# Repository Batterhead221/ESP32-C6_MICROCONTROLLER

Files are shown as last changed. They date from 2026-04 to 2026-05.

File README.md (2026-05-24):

# ESP32-C6_MICROCONTROLLER

<p align="center">
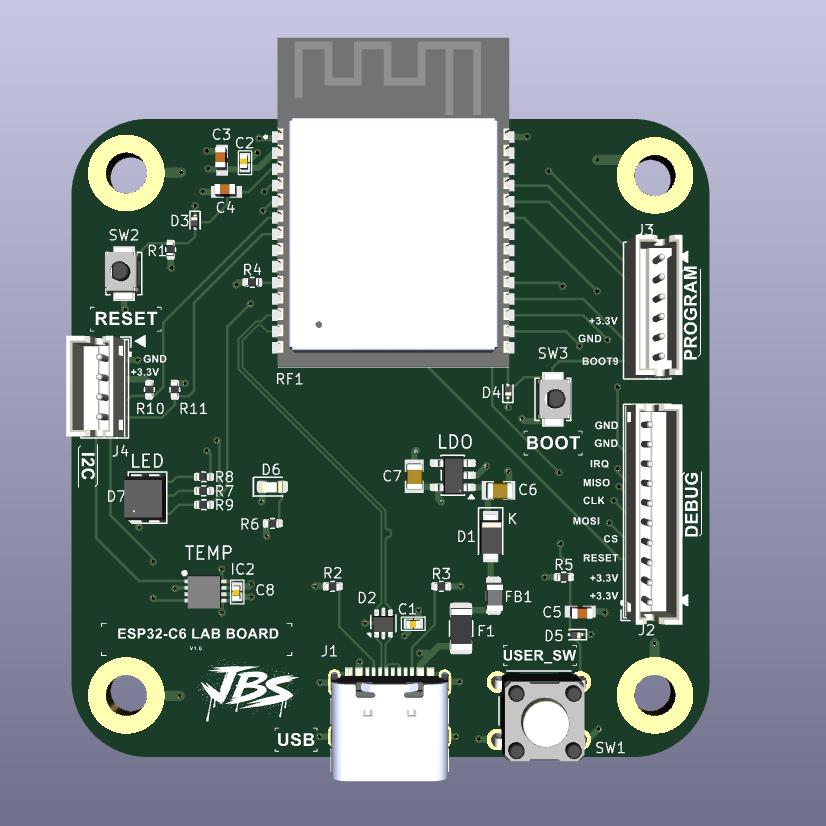
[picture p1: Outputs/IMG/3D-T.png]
ESP32-C6_MICROCONTROLLER top 3D board render
  
</p>

<p align="center">
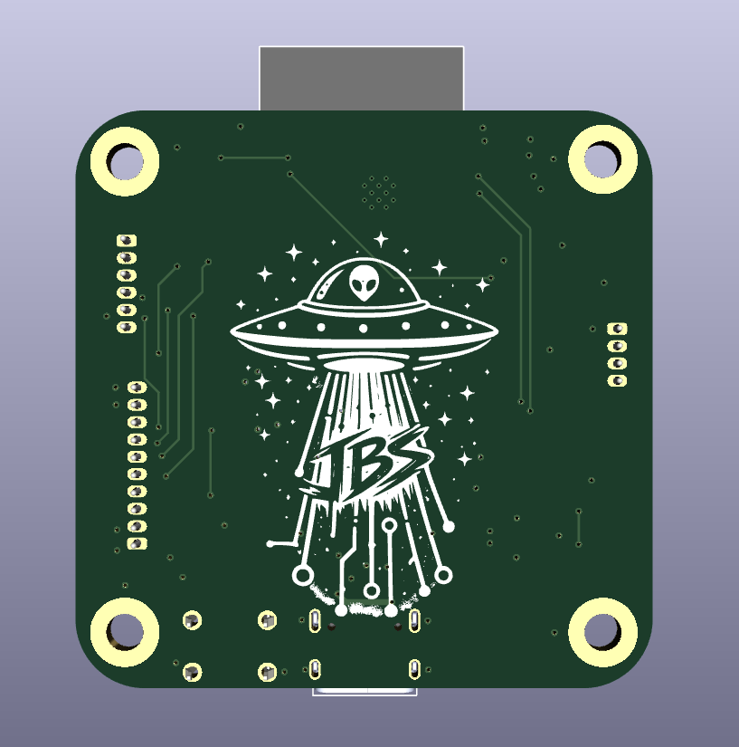
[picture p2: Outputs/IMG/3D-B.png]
ESP32-C6_MICROCONTROLLER bottom 3D board render
  
</p>

Custom ESP32-C6 development board with USB-C power, RGB status LED, user input, I2C expansion, OLED support, UART programming access, and onboard temperature/humidity sensing.

This board is a small ESP32-C6 bring-up and sensor demo platform. It was designed to verify core power, boot/programming flow, GPIO, RGB LED control, I2C device detection, OLED output, and live environmental sensor readings.

## Project Status

Bring-up demo verified.

The board has successfully run a combined test with:

- RGB LED control
- User button input
- I2C bus scan
- OLED output
- Live temperature/humidity readout
- UART programming through the J3 program header

## Demo Features

- ESP32-C6 microcontroller core
- USB-C power input
- 3.3V regulation
- RGB status LED
- User button
- I2C expansion header
- OLED display support
- Onboard temperature/humidity sensor
- UART programming/debug header
- Reset and boot control for bring-up

## System Role

```text
USB-C / bench power
        ↓
ESP32-C6_MICROCONTROLLER
        ↓ I2C
OLED display + temp/humidity sensor
        ↓
bring-up demo / serial debug output
```

## Key Specs

| Item | Value |
|---|---|
| MCU | ESP32-C6 |
| Main rail | +3.3V |
| Power input | USB-C |
| Programming path verified | UART through J3 program header |
| Display interface | I2C OLED |
| Sensor interface | I2C temp/humidity sensor |
| OLED address | `0x3C` |
| Temp/humidity sensor address | `0x44` |
| RGB LED behavior | Active-low |
| Board role | ESP32-C6 bring-up/demo board |

## Verified Working

- USB-C power input
- 3.3V regulation
- ESP32-C6 boot from flash
- UART programming through J3
- Reset button
- Boot button/manual boot sequence
- User button
- RGB LED
- I2C bus
- OLED display at `0x3C`
- Temperature/humidity sensor at `0x44`

## Verified GPIO Map

| GPIO | Function |
|---:|---|
| GPIO3 | RGB red |
| GPIO4 | RGB green |
| GPIO5 | RGB blue |
| GPIO23 | User switch |
| GPIO6 | I2C SDA |
| GPIO7 | I2C SCL |

## RGB LED Notes

The RGB LED is active-low.

```text
GPIO LOW  → LED color ON
GPIO HIGH → LED color OFF
```

Firmware should invert the LED logic when controlling the status LED.

## I2C Devices

The following I2C devices were detected during bring-up:

| Address | Device |
|---:|---|
| `0x3C` | OLED display |
| `0x44` | Temperature/humidity sensor |

## Sample Verified Sensor Reading

Example live reading from bring-up:

```text
Temperature: 29.2 C
Humidity:    35.0 %RH
```

## UART Programming Notes

UART programming through the **J3 program header** is working.

Working connections:

| USB-UART adapter | ESP32-C6 board |
|---|---|
| TX | ESP_RXD |
| RX | ESP_TXD |
| GND | GND |

## Manual Upload Sequence

Current working upload sequence:

1. Hold **BOOT**.
2. Start upload.
3. Tap **RESET** when the tool begins connecting.
4. Release **BOOT** after connection.
5. Press **RESET** after upload to run the application.

## Native USB Status

Native USB enumeration still needs separate debug and validation.

Current programming flow uses UART through the J3 program header.

## Bring-Up Checklist

1. Inspect USB-C and regulator soldering.
2. Power from USB-C and confirm +3.3V.
3. Connect USB-UART adapter to J3.
4. Use the manual BOOT/RESET upload sequence.
5. Verify boot from flash.
6. Run I2C scanner.
7. Confirm OLED at `0x3C`.
8. Confirm temp/humidity sensor at `0x44`.
9. Verify RGB LED channels.
10. Verify user button input.
11. Run combined OLED + sensor + LED demo.

## Open Items

- Validate native USB enumeration.
- Improve programming flow beyond manual UART boot sequence.
- Add screenshots/photos of OLED and sensor demo.
- Add firmware example to the repository.

## Repository Output Images

Expected image paths for GitHub README rendering:

```text
Outputs/
  IMG/
    3D-T.png
    3D-B.png
    SCHEMATIC.png
    L1-SIG.png
    L2-GND.png
```

## Safety / Design Note

ESP32-C6_MICROCONTROLLER is a low-voltage development board. Verify regulator output, USB wiring, and UART adapter voltage level before connecting external hardware.

Designed & engineered by Brandon Shelly.

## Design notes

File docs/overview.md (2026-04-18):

#ESP32-C6_BOARD

## OVERVIEW

EMBEDDED HARDWARE / MICROCONTROLLER PCB DESIGN PROJECT

WI-FI / BLUETOOTH CUSTOM EMBEDDED MICROCONTROLLER PCB DESIGNED FOR BRING-UP, DEBUG, AND INTERFACE VALIDATION

## CREATED TO DEMONSTRATE:
- SCHEMATIC CAPTURE
- PCB LAYOUT
- DFM-AWARE DESIGN
- BRING-UP AND TEST PLANNING
- HARDWARE DOCUMENTATION

## KEY FEATURES
- [ESP32C6]
- [USB-C POWER INPUT]
- [UART]
- [DEBUG / PROGRAMMING INTERFACE]
- [TEMP/WI-FI/BLUETOOTH]

## PROJECT STATUS
REVISION: V1.0  
STATUS: WORKING

DESIGNED & ENGINEERED BY BRANDON SHELLY

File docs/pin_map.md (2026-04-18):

GPIO3 = RED
GPIO4 = GREEN
GPIO5 = BLUE
GPIO23 = USER BUTTON
GPIO6 = SDA
GPIO7 = SCL
OLED = 0x3C
HDC302x = 0x44

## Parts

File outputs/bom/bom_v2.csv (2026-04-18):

BOM_V2
BOM
Id | Designator | Footprint | Quantity | Designation | Supplier and ref | LCSC
1 | J3 | JST_ZH_B6B-ZR_1x06_P1.50mm_Vertical | 1 | PROGRAM | DNP | DNP
2 | J2 | JST_ZH_B10B-ZR_1x10_P1.50mm_Vertical | 1 | DEBUG | DNP | DNP
3 | SW2 | SW_SPST_B3U-1000P | 1 | RESET | B3U-1100P-B | C4364316
4 | USER_SW | SW_TH_Tactile_Omron_B3F-100x | 1 | SW1 | DNP | DNP
5 | SW3 | SW_SPST_B3U-1000P | 1 | BOOT | B3U-1100P-B | C4364316
6 | C3,C5,C4 | CAP 0603 | 3 | 1U | CC0603KRX7R9BB105 | C559769
7 | C2,C1,C8 | CAP 0402 | 3 | 100N | CC0402KRX7R9BB104 | C131394
8 | U1 | SOT-23-5 | 1 | LDO | AP2112K-3.3TRG1 | C23380830
9 | J4 | JST_ZH_B4B-ZR_1x04_P1.50mm_Vertical | 1 | I2C | DNP | DNP
10 | D1 | Nexperia_CFP3_SOD-123W | 1 | 1N5817 | 1N5817W | C727113
11 | R7,R9,R8,R6 | R_0402_1005Metric | 4 | 1K | RC0402JR-071KL | C105637
12 | F1 | Fuse_1206_3216Metric | 1 | 1A | JFC1206-1100FS | C136343
13 | R2,R3 | R_0402_1005Metric | 2 | 5K1 | 0402WGF5101TCE | C25905
14 | C7,C6 | 1UF 0805 | 2 | 1U | CC0805KKX7R8BB105 | C91186
15 | U2 | SON50P250X250X80-9N-D | 1 | LDO | HDC3020DEFR | C7472806
16 | R10,R11 | R_0402_1005Metric | 2 | 2K2 | AC0402FR-072K2L | C144773
17 | FB1 | L_0805_2012Metric | 1 | 22 OHM FERRITE BEAD | BLM21PG220SN1D | C88993
18 | R1,R5,R4 | R_0402_1005Metric | 3 | 10K | 0402 ±1% 10K | C2889342
19 | D4,D3,D5 | D_SOD-923 | 3 | ESD9B3.3 | ESD9B3.3ST5G | C96512
20 | D7 | LED_Cree-PLCC4_3.2x2.8mm_CCW | 1 | RGB_LED | CLV1L-FKB-CJ1N1E1BB7B3B3
21 | D2 | SOT-666 | 1 | USBLC6-2P6 | USBLC6-2P6 | C15999
22 | J1 | USB_C_Receptacle_G-Switch_GT-USB-7010ASV | 1 | USB_C | GT-USB-7010ASV | C2988369
23 | D6 | LED_0603_1608Metric | 1 | GREEN | YLED0603G | C19273151
24 | U3 | XCVR_ESP32-C6-WROOM-1-N8 | 1 | ESP32-C6-WROOM-1-N8 | ESP32-C6-WROOM-1-N8 | C5366877

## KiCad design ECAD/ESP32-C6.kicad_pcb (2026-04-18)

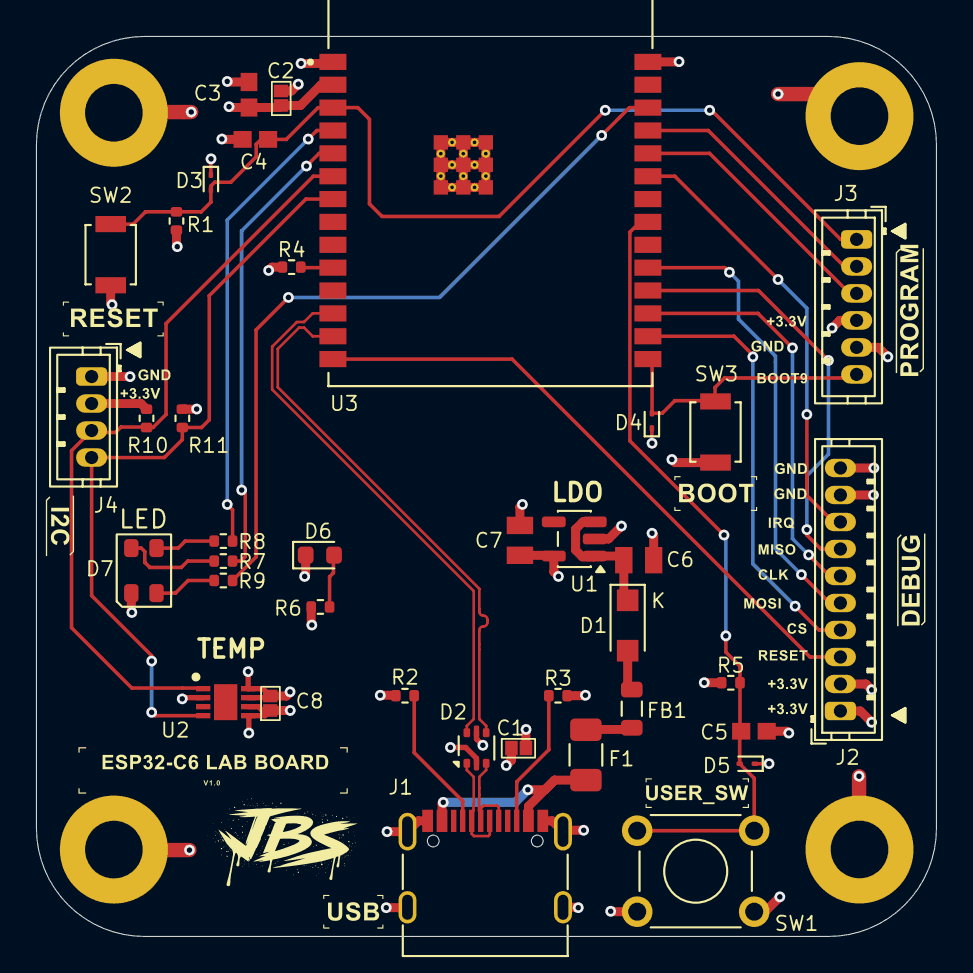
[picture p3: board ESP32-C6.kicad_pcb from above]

Board: 4 copper layers, 50.0 x 50.0 mm, 42 parts (0 on the bottom side), 33 nets.

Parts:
C1, C2, C8: 100N; CAP 0402
C3, C4, C5: 1U; CAP 0603
C6, C7: 1U; 1UF 0805
D1: 1N5817; Nexperia_CFP3_SOD-123W
D2: USBLC6-2P6; SOT-666
D3, D4, D5: ESD9B3.3; D_SOD-923
D6: GREEN; LED_0603_1608Metric
D7: RBG_LED; LED_Cree-PLCC4_3.2x2.8mm_CCW
F1: 1A; Fuse_1206_3216Metric
FB1: 22; L_0805_2012Metric
H1, H2, H3, H4: M3; MountingHole_3.2mm_Pad
J1: USB_C; USB_C_Receptacle_G-Switch_GT-USB-7010ASV
J2: SWD; JST_ZH_B10B-ZR_1x10_P1.50mm_Vertical
J3: PROGRAM; JST_ZH_B6B-ZR_1x06_P1.50mm_Vertical
J4: S2C; JST_ZH_B4B-ZR_1x04_P1.50mm_Vertical
R1, R4, R5: 10K; R_0402_1005Metric
R2, R3: 5K1; R_0402_1005Metric
R6, R7, R8, R9: 1K; R_0402_1005Metric
R10, R11: 2K2; R_0402_1005Metric
SW1: SW_DPST; SW_TH_Tactile_Omron_B3F-100x
SW2: RESET; SW_SPST_B3U-1000P
SW3: SW_SPST_B3U-1000P
U1: LDO; SOT-23-5
U2: HDC3020DEFR; SON50P250X250X80-9N-D
U3: ESP32-C6-WROOM-1-N8; XCVR_ESP32-C6-WROOM-1-N8

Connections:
+3.3V: C1.1, C2.1, C3.1, C7.1, C8.1, D2.5 (Vbus), D7.1 (A), J2.1, J2.2, J3.4, J4.2, R1.1, R4.1, R5.1, R6.2, R10.1, R11.1, U1.5 (VOUT), U2.5 (VDD), U2.6 (~RESET), U3.2 (3V3)
+5V: C6.1, D1.1 (K), U1.1 (VIN), U1.3 (EN)
/BOOT9: D4.2 (A2), J3.6, SW3.2 (B), U3.15 (IO9)
/B_LED: R7.2, U3.5 (IO5)
/CC1: J1.A5 (CC1), R2.1
/CC2: J1.B5 (CC2), R3.1
/CLK: J2.6, U3.17 (IO19)
/CS: J2.4, U3.16 (IO18)
/D+: D2.3 (I/O2), J1.A6 (D+), J1.B6 (D+)
/D-: D2.1 (I/O1), J1.A7 (D-), J1.B7 (D-)
/ESP_EN: C4.1, D3.2 (A2), J3.1, R1.2, SW2.2 (B), U3.3 (EN)
/ESP_RXD: J3.3, U3.24 (RXD0/GPIO17)
/ESP_TXD: J3.2, U3.25 (TXD0/GPIO16)
/G_LED: R8.2, U3.4 (IO4)
/IRQ: J2.8, U3.23 (IO15)
/MISO: J2.7, U3.18 (IO20)
/MOSI: J2.5, U3.19 (IO21)
/RESET: J2.3, U3.14 (IO13)
/R_RED: R9.2, U3.26 (IO3)
/SCL: J4.4, R11.2, U2.4 (SCL), U3.7 (IO7)
/SDA: J4.3, R10.2, U2.1 (SDA), U3.6 (IO6)
/USB_D+: D2.4 (I/O2+), U3.13 (IO12)
/USB_D-: D2.6 (I/O1+), U3.12 (IO11)
/USR_SW: C5.1, D5.2 (A2), R5.2, SW1.2 (B), U3.21 (IO23)
GND: C1.2, C2.2, C3.2, C4.2, C5.2, C6.2, C7.2, C8.2, D2.2 (GND), D3.1 (A1), D4.1 (A1), D5.1 (A1), D6.1 (K), H1.1, H2.2, H3.4, H4.3, J1.A1 (GND), J1.A12 (GND), J1.B1 (GND), J1.B12 (GND), J1.S1 (SHIELD), J2.9, J2.10, J3.5, J4.1, R2.2, R3.2, SW1.1 (A), SW2.1 (A), SW3.1 (A), U1.2 (GND), U2.2 (ADDR), U2.7 (ADDR1), U2.8 (GND), U3.1 (GND), U3.28 (GND__1), U3.29 (GND__10)
unnamed: D1.2 (A), FB1.2
unnamed: D6.2 (A), R6.1
unnamed: D7.4 (BK), R7.1
unnamed: D7.3 (GK), R8.1
unnamed: D7.2 (RK), R9.1
unnamed: F1.1, J1.A4 (VBUS), J1.A9 (VBUS), J1.B4 (VBUS), J1.B9 (VBUS)
unnamed: F1.2, FB1.1
unnamed: R4.2, U3.10 (IO8)

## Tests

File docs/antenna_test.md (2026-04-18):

### RF / WIRELESS STATUS

* ESP32-C6-WROOM-1 PCB ANTENNA VERIFIED FUNCTIONAL
* WI-FI NETWORK SCAN COMPLETED SUCCESSFULLY
* WI-FI STATION CONNECTION VERIFIED
* DHCP / IP ACQUISITION VERIFIED
* EXAMPLE CONNECTED WI-FI RSSI OBSERVED: **-40 DBM**
* BLE ADVERTISING VERIFIED
* BLE PHONE CONNECTION VERIFIED

### CURRENT RF STATUS

REV A WIRELESS FUNCTIONALITY HAS BEEN VERIFIED FAR ENOUGH TO SUPPORT CONTINUED DEVELOPMENT AND APPLICATION DEMOS.

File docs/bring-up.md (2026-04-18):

### VERIFIED WORKING

* USB-C POWER INPUT
* 3.3V REGULATION
* ESP32-C6 BOOT FROM FLASH
* UART PROGRAMMING THROUGH J3
* RESET BUTTON
* USER BUTTON
* RGB LED
* I2C BUS
* OLED DISPLAY AT `0X3C`
* TEMP/HUM SENSOR AT `0X44`
* WI-FI SCAN VERIFIED
* MULTIPLE SSIDS DETECTED WITH NORMAL RSSI VALUES

### VERIFIED GPIO MAP

* `GPIO3` = RED
* `GPIO4` = GREEN
* `GPIO5` = BLUE
* `GPIO23` = USER SWITCH
* `GPIO6` = SDA
* `GPIO7` = SCL

### RGB LED NOTES

THE RGB LED IS **ACTIVE-LOW**:

* `LOW` = ON
* `HIGH` = OFF

### UART PROGRAMMING NOTES

UART PROGRAMMING THROUGH THE **J3 PROGRAM HEADER** IS WORKING.

WORKING CONNECTIONS:

* USB-UART `TX` -> BOARD `ESP_RXD`
* USB-UART `RX` -> BOARD `ESP_TXD`
* USB-UART `GND` -> BOARD `GND`

CURRENT WORKING UPLOAD SEQUENCE:

1. HOLD **BOOT**
2. START UPLOAD
3. TAP **RESET** WHEN THE TOOL BEGINS CONNECTING
4. RELEASE **BOOT** AFTER CONNECTION
5. PRESS **RESET** AFTER UPLOAD TO RUN THE APPLICATION

### I2C DEVICE DETECTION

THE FOLLOWING I2C DEVICES WERE DETECTED DURING BRING-UP:

* `0X3C` = OLED
* `0X44` = TEMP/HUM SENSOR

### SAMPLE VERIFIED SENSOR READING

* **29.2C**
* **35.0% RH**

## REV-A NOTES

### WHAT WORKED WELL

* CORE POWER-UP AND 3.3V REGULATION WERE GOOD
* ESP32-C6 BOOTED SUCCESSFULLY AND RAN APPLICATION CODE
* UART PROGRAMMING THROUGH THE J3 HEADER WORKED
* RGB LED, USER BUTTON, OLED, AND I2C SENSOR WERE ALL VERIFIED IN HARDWARE
* THE BOARD WAS ABLE TO RUN A COMBINED DEMO SHOWING LIVE TEMP / HUM DATA ON THE OLED

### WHAT TOOK TOO LONG

* TOO MUCH TIME WAS SPENT CHASING HOST-SIDE DRIVER / USB ISSUES BEFORE FALLING BACK TO THE KNOWN-GOOD UART PROGRAMMING PATH
* INITIAL BRING-UP WOULD HAVE MOVED FASTER WITH A MORE DELIBERATE STEP-BY-STEP VALIDATION PLAN FROM THE START
* LED / GPIO MAPPING HAD TO BE VERIFIED MANUALLY DURING TESTING INSTEAD OF BEING IMMEDIATELY OBVIOUS FROM A SINGLE BRING-UP REFERENCE

### WHAT MADE BRING-UP HARDER THAN IT NEEDED TO BE

* NATIVE USB ENUMERATION DID NOT COME UP CLEANLY DURING INITIAL TESTING
* PROGRAMMING CURRENTLY REQUIRES A MANUAL BOOT / RESET SEQUENCE THROUGH THE UART HEADER
* WITHOUT AUTO-RESET / AUTO-BOOT CONTROL, THE PROGRAM / TEST LOOP IS SLOWER AND MORE ERROR-PRONE
* A FEW SIGNAL / GPIO DETAILS NEEDED TO BE CONFIRMED IN HARDWARE INSTEAD OF BEING PRE-DOCUMENTED AS A BRING-UP MAP

### WHAT I WOULD NOT DO THE SAME WAY AGAIN

* I WOULD NOT RELY ON MEMORY OR SCATTERED NOTES FOR FIRST BRING-UP PIN MAPPING
* I WOULD CREATE A SMALL, DEDICATED BRING-UP TABLE FOR GPIO, I2C ADDRESSES, TEST POINTS, AND PROGRAMMING FLOW BEFORE THE BOARD ARRIVES
* I WOULD PLAN FOR A FASTER FIRST-FLASH / RESET FLOW SO THAT FIRMWARE ITERATION IS LESS FRAGILE
* I WOULD TREAT A WORKING UART PROGRAMMING PATH AS THE FIRST RECOVERY / VALIDATION TARGET IMMEDIATELY

## REV B CHANGES

### PROGRAMMING / DEBUG IMPROVEMENTS

* IMPROVE NATIVE USB IMPLEMENTATION / VALIDATION SO USB ENUMERATION IS A FIRST-CLASS PROGRAMMING PATH
* CONSIDER ADDING OR IMPROVING AUTO-PROGRAM / AUTO-RESET SUPPORT FOR FASTER FLASHING
* MAKE THE PROGRAMMING / DEBUG HEADER MORE OBVIOUS AND EASIER TO USE DURING BENCH TESTING
* ADD CLEARER SILK FOR PROGRAM HEADER PIN FUNCTIONS

### TEST / VALIDATION IMPROVEMENTS

* ADD MORE CONVENIENT TEST ACCESS FOR KEY SIGNALS USED DURING FIRST BRING-UP
* ADD OR REPOSITION TEST POINTS FOR FASTER POWER, RESET, BOOT, AND COMMUNICATION CHECKS
* CREATE A DEDICATED BRING-UP REFERENCE TABLE IN THE REPO BEFORE ASSEMBLY

### LAYOUT / USABILITY IMPROVEMENTS

* REVIEW CONNECTOR PLACEMENT AND ACCESSIBILITY FOR BENCH WIRING
* REVIEW SILK LABEL SIZE / PLACEMENT FOR FASTER IDENTIFICATION DURING TESTING
* MAKE ANY SMALL CLEANUP CHANGES TO IMPROVE BENCH TOP USABILITY AND REDUCE CONFUSION

### FIRMWARE / DEMO IMPROVEMENTS

* ADD A CLEANER OLED DEMO SCREEN FLOW
* EXPAND THE SENSOR / STATUS DEMO INTO A MORE PRESENTABLE SHOWCASE APPLICATION

## VERIFIED WORKING

* USB-C POWER INPUT
* 3.3V REGULATION
* ESP32-C6 BOOT FROM FLASH
* UART PROGRAMMING THROUGH J3
* RESET BUTTON
* USER BUTTON
* RGB LED
* I2C BUS
* OLED DISPLAY AT `0X3C`
* TEMP / HUM SENSOR AT `0X44`
* COMBINED OLED + BUTTON + RGB + SENSOR DEMO

## OPEN ISSUES

* NATIVE USB ENUMERATION STILL NEEDS SEPARATE DEBUG / VALIDATION
* PROGRAMMING FLOW IS CURRENTLY MANUAL THROUGH THE UART HEADER
* AUTO-RESET / AUTO-PROGRAM WORKFLOW HAS NOT YET BEEN IMPLEMENTED OR VERIFIED
* LONGER-RUN VALIDATION AND ADDITIONAL SYSTEM TESTING STILL NEED TO BE COMPLETED

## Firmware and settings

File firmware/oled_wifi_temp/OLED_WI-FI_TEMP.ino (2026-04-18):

#include <Wire.h>
#include <WiFi.h>
#include <Adafruit_GFX.h>
#include <Adafruit_SSD1306.h>

// =========================
// WIFI SETTINGS
// =========================
const char* WIFI_SSID = "SchmungusAmongus";
const char* WIFI_PASS = "95ModelT";

// =========================
// VERIFIED BOARD MAP
// =========================
const int LED_R   = 3;   // active-low
const int LED_G   = 4;   // active-low
const int LED_B   = 5;   // active-low
const int I2C_SDA = 6;
const int I2C_SCL = 7;
const int USR_SW  = 23;  // active-low button with INPUT_PULLUP

#define OLED_ADDR      0x3C
#define HDC302X_ADDR   0x44
#define SCREEN_WIDTH   128
#define SCREEN_HEIGHT  64
#define OLED_RESET     -1

Adafruit_SSD1306 display(SCREEN_WIDTH, SCREEN_HEIGHT, &Wire, OLED_RESET);

bool oledOk = false;
bool wifiConnected = false;

float tempC = 0.0f;
float humidity = 0.0f;

unsigned long lastSensorRead = 0;
unsigned long lastStatusPrint = 0;
unsigned long lastButtonDebounce = 0;

int currentScreen = 0;
int lastButtonState = HIGH;

// =========================
// LED HELPERS (ACTIVE-LOW)
// =========================
void allOff() {
  digitalWrite(LED_R, HIGH);
  digitalWrite(LED_G, HIGH);
  digitalWrite(LED_B, HIGH);
}

void setRed(bool on)   { digitalWrite(LED_R, on ? LOW : HIGH); }
void setGreen(bool on) { digitalWrite(LED_G, on ? LOW : HIGH); }
void setBlue(bool on)  { digitalWrite(LED_B, on ? LOW : HIGH); }

void updateStatusLed() {
  bool buttonPressed = (digitalRead(USR_SW) == LOW);

  allOff();

  if (buttonPressed) {
    setRed(true);
    return;
  }

  if (wifiConnected) {
    setGreen(true);
  } else {
    setBlue(true);
  }
}

// =========================
// HDC302X READ
// =========================
bool readHDC302x(float &tC, float &rh) {
  uint8_t buf[6];

  Wire.beginTransmission(HDC302X_ADDR);
  Wire.write(0x24);
  Wire.write(0x00);
  if (Wire.endTransmission() != 0) {
    return false;
  }

  delay(25);

  if (Wire.requestFrom(HDC302X_ADDR, 6) != 6) {
    return false;
  }

  for (int i = 0; i < 6; i++) {
    buf[i] = Wire.read();
  }

  uint16_t rawTemp = ((uint16_t)buf[0] << 8) | buf[1];
  uint16_t rawHum  = ((uint16_t)buf[3] << 8) | buf[4];

  tC = ((float)rawTemp / 65535.0f) * 175.0f - 45.0f;
  rh = ((float)rawHum  / 65535.0f) * 100.0f;

  return true;
}

// =========================
// OLED
// =========================
void drawHeader(const __FlashStringHelper* title) {
  display.setTextSize(1);
  display.setTextColor(SSD1306_WHITE);
  display.setCursor(0, 0);
  display.println(title);
  display.drawLine(0, 9, 127, 9, SSD1306_WHITE);
}

void drawScreen0() {
  display.clearDisplay();
  drawHeader(F("ESP32-C6 DEMO"));

  display.setCursor(0, 14);
  display.print(F("TEMP: "));
  display.print(tempC, 1);
  display.println(F(" C"));

  display.setCursor(0, 26);
  display.print(F("HUM : "));
  display.print(humidity, 1);
  display.println(F(" %"));

  display.setCursor(0, 40);
  display.print(F("WIFI: "));
  display.println(wifiConnected ? F("OK") : F("FAIL"));

  display.setCursor(0, 52);
  display.print(F("BTN : "));
  display.println((digitalRead(USR_SW) == LOW) ? F("PRESSED") : F("RELEASED"));

  display.display();
}

void drawScreen1() {
  display.clearDisplay();
  drawHeader(F("WIFI STATUS"));

  display.setCursor(0, 14);
  display.print(F("SSID: "));
  if (wifiConnected) {
    display.println(WIFI_SSID);
  } else {
    display.println(F("NOT CONNECTED"));
  }

  display.setCursor(0, 28);
  display.print(F("IP: "));
  if (wifiConnected) {
    display.println(WiFi.localIP());
  } else {
    display.println(F("--"));
  }

  display.setCursor(0, 42);
  display.print(F("RSSI: "));
  if (wifiConnected) {
    display.print(WiFi.RSSI());
    display.println(F(" dBm"));
  } else {
    display.println(F("--"));
  }

  display.display();
}

void drawScreen2() {
  display.clearDisplay();
  drawHeader(F("BOARD MAP"));

  display.setCursor(0, 14);
  display.println(F("R=3  G=4  B=5"));
  display.setCursor(0, 26);
  display.println(F("BTN=23"));
  display.setCursor(0, 38);
  display.println(F("SDA=6  SCL=7"));
  display.setCursor(0, 50);
  display.println(F("OLED=3C HDC=44"));

  display.display();
}

void updateDisplay() {
  if (!oledOk) return;

  switch (currentScreen) {
    case 0: drawScreen0(); break;
    case 1: drawScreen1(); break;
    case 2: drawScreen2(); break;
    default: drawScreen0(); break;
  }
}

// =========================
// WIFI
// =========================
void initWiFi() {
  Serial.println(F("=== INIT WIFI ==="));
  Serial.print(F("SSID: "));
  Serial.println(WIFI_SSID);

  WiFi.mode(WIFI_STA);
  delay(500);

  WiFi.disconnect(true, true);
  delay(1000);

  Serial.println(F("CALLING WiFi.begin()"));
  WiFi.begin(WIFI_SSID, WIFI_PASS);

  int tries = 0;
  while (WiFi.status() != WL_CONNECTED && tries < 30) {
    delay(500);
    Serial.print(F("."));
    tries++;
  }
  Serial.println();

  wl_status_t st = WiFi.status();
  wifiConnected = (st == WL_CONNECTED);

  Serial.print(F("FINAL WIFI STATUS: "));
  Serial.println((int)st);

  if (wifiConnected) {
    Serial.println(F("WIFI CONNECTED"));
    Serial.print(F("IP: "));
    Serial.println(WiFi.localIP());
    Serial.print(F("RSSI: "));
    Serial.print(WiFi.RSSI());
    Serial.println(F(" dBm"));
  } else {
    Serial.println(F("WIFI FAILED"));
  }
}

// =========================
// BUTTON
// =========================
void handleButton() {
  int reading = digitalRead(USR_SW);

  if (reading != lastButtonState && millis() - lastButtonDebounce > 25) {
    lastButtonDebounce = millis();
    lastButtonState = reading;

    if (reading == LOW) {
      currentScreen++;
      if (currentScreen > 2) currentScreen = 0;

      Serial.print(F("SCREEN -> "));
      Serial.println(currentScreen);
      updateDisplay();
    }
  }
}

// =========================
// SETUP / LOOP
// =========================
void setup() {
  Serial.begin(115200);
  delay(1500);

  pinMode(LED_R, OUTPUT);
  pinMode(LED_G, OUTPUT);
  pinMode(LED_B, OUTPUT);
  pinMode(USR_SW, INPUT_PULLUP);
  allOff();

  Wire.begin(I2C_SDA, I2C_SCL);

  oledOk = display.begin(SSD1306_SWITCHCAPVCC, OLED_ADDR);
  Serial.println(oledOk ? F("OLED OK") : F("OLED FAIL"));

  Serial.println();
  Serial.println(F("=== ESP32-C6 WIFI SENSOR DEMO ==="));

  // quick LED self test
  setRed(true);   delay(120); setRed(false);
  setGreen(true); delay(120); setGreen(false);
  setBlue(true);  delay(120); setBlue(false);

  initWiFi();

  if (readHDC302x(tempC, humidity)) {
    Serial.print(F("TEMP_C: "));
    Serial.print(tempC, 2);
    Serial.print(F(" RH_%: "));
    Serial.println(humidity, 2);
  } else {
    Serial.println(F("HDC READ FAIL"));
  }

  updateStatusLed();
  updateDisplay();
}

void loop() {
  handleButton();

  if (millis() - lastSensorRead >= 1000) {
    lastSensorRead = millis();

    float newTemp = 0.0f;
    float newHum = 0.0f;
    if (readHDC302x(newTemp, newHum)) {
      tempC = newTemp;
      humidity = newHum;
    }

    wifiConnected = (WiFi.status() == WL_CONNECTED);
    updateStatusLed();
    updateDisplay();
  }

  if (millis() - lastStatusPrint >= 3000) {
    lastStatusPrint = millis();

    Serial.print(F("TEMP_C: "));
    Serial.print(tempC, 2);
    Serial.print(F(" | RH_%: "));
    Serial.print(humidity, 2);
    Serial.print(F(" | WIFI: "));
    Serial.print(wifiConnected ? F("OK") : F("FAIL"));

    if (wifiConnected) {
      Serial.print(F(" | IP: "));
      Serial.print(WiFi.localIP());
      Serial.print(F(" | RSSI: "));
      Serial.print(WiFi.RSSI());
      Serial.print(F(" dBm"));
    }

    Serial.print(F(" | SCREEN: "));
    Serial.println(currentScreen);
  }
}

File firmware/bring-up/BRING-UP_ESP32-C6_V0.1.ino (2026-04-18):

#include <Wire.h>
#include <Adafruit_GFX.h>
#include <Adafruit_SSD1306.h>

const int LED_R = 3;
const int LED_G = 4;
const int LED_B = 5;
const int USR_SW = 23;

const int I2C_SDA = 6;
const int I2C_SCL = 7;

#define SCREEN_WIDTH 128
#define SCREEN_HEIGHT 64
#define OLED_RESET -1
#define OLED_ADDR 0x3C
#define HDC302X_ADDR 0x44

Adafruit_SSD1306 display(SCREEN_WIDTH, SCREEN_HEIGHT, &Wire, OLED_RESET);

bool oledOk = false;

void allOff() {
  digitalWrite(LED_R, HIGH);
  digitalWrite(LED_G, HIGH);
  digitalWrite(LED_B, HIGH);
}

void setRed(bool on)   { digitalWrite(LED_R, on ? LOW : HIGH); }
void setGreen(bool on) { digitalWrite(LED_G, on ? LOW : HIGH); }
void setBlue(bool on)  { digitalWrite(LED_B, on ? LOW : HIGH); }

bool readHDC302x(float &tempC, float &rh) {
  uint8_t buf[6];

  // Trigger on-demand measurement: 0x24 0x00
  Wire.beginTransmission(HDC302X_ADDR);
  Wire.write(0x24);
  Wire.write(0x00);
  if (Wire.endTransmission() != 0) {
    return false;
  }

  delay(25);

  if (Wire.requestFrom(HDC302X_ADDR, 6) != 6) {
    return false;
  }

  for (int i = 0; i < 6; i++) {
    buf[i] = Wire.read();
  }

  uint16_t rawTemp = ((uint16_t)buf[0] << 8) | buf[1];
  uint16_t rawHum  = ((uint16_t)buf[3] << 8) | buf[4];

  tempC = ((float)rawTemp / 65535.0f) * 175.0f - 45.0f;
  rh    = ((float)rawHum  / 65535.0f) * 100.0f;

  return true;
}

void showOLED(float tempC, float rh, bool pressed) {
  if (!oledOk) return;

  display.clearDisplay();
  display.setTextColor(SSD1306_WHITE);

  display.setTextSize(1);
  display.setCursor(0, 0);
  display.println("ESP32-C6 TEMP DEMO");

  display.setTextSize(2);
  display.setCursor(0, 16);
  display.print(tempC, 1);
  display.println(" C");

  display.setCursor(0, 40);
  display.print(rh, 1);
  display.println(" %");

  display.setTextSize(1);
  display.setCursor(92, 0);
  display.print("BTN:");
  display.println(pressed ? "P" : "R");

  display.display();
}

void setup() {
  Serial.begin(115200);

  pinMode(LED_R, OUTPUT);
  pinMode(LED_G, OUTPUT);
  pinMode(LED_B, OUTPUT);
  pinMode(USR_SW, INPUT_PULLUP);
  allOff();

  Wire.begin(I2C_SDA, I2C_SCL);

  oledOk = display.begin(SSD1306_SWITCHCAPVCC, OLED_ADDR);

  if (oledOk) {
    setGreen(true);
    delay(150);
    setGreen(false);
  } else {
    setRed(true);
    delay(150);
    setRed(false);
  }

  Serial.println();
  Serial.println("ESP32-C6 HDC302X + OLED DEMO START");
}

void loop() {
  bool pressed = (digitalRead(USR_SW) == LOW);
  float tempC = 0.0f;
  float rh = 0.0f;

  if (readHDC302x(tempC, rh)) {
    Serial.print("TEMP_C: ");
    Serial.print(tempC, 2);
    Serial.print("  RH_%: ");
    Serial.println(rh, 2);

    showOLED(tempC, rh, pressed);

    if (pressed) {
      setRed(true);
    } else {
      setRed(false);
    }

    setBlue(true);
    delay(50);
    setBlue(false);
  } else {
    Serial.println("HDC302X READ FAILED");
    setRed(true);
    delay(100);
    setRed(false);
  }

  delay(1000);
}

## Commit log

2026-04-18 file path restructure
    [ESP32-C6.kicad_pcb, ESP32-C6.kicad_sch, bom_v2.csv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]
2026-05-03 folder restructure
    [ESP32-C6.kicad_pcb, ESP32-C6.kicad_sch, bom_v2.csv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]
2026-05-13 Revised repo
    [ESP32-C6.kicad_pcb, ESP32-C6.kicad_sch]
